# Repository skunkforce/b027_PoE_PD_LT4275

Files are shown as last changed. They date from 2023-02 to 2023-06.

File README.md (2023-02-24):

# edgy_board number b027
This design is part of the [edgy board project](https://github.com/skunkforce/edgy_boards). It provides a PoE Power Device capable of 100W. 

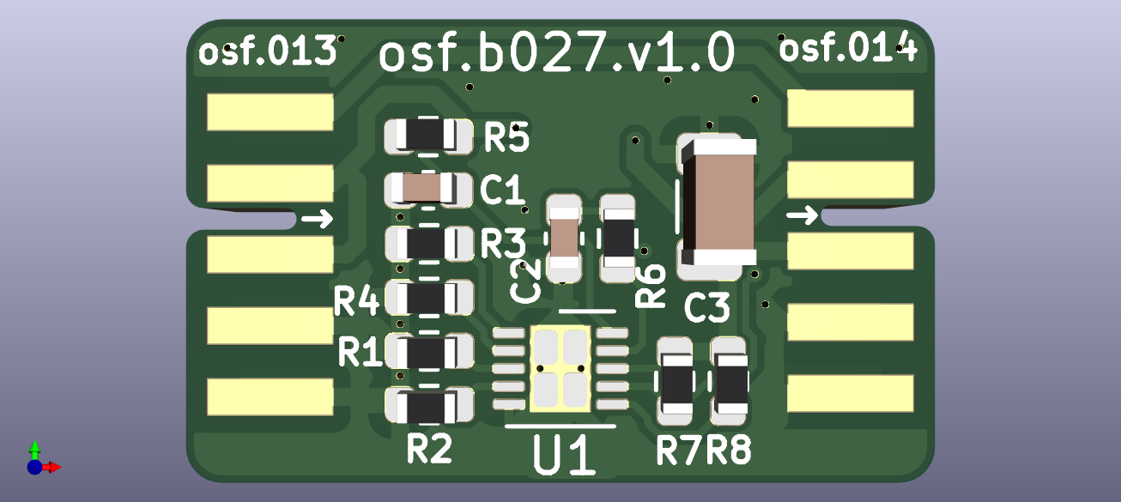
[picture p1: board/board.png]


# getting started
This repository uses submodules. After cloning use the command 

```$ git submodule update --init --recursive```

to pull the submodules before opening the project with kicad. 

# Tests
Tests can be found in [TESTS.md](TESTS.md)

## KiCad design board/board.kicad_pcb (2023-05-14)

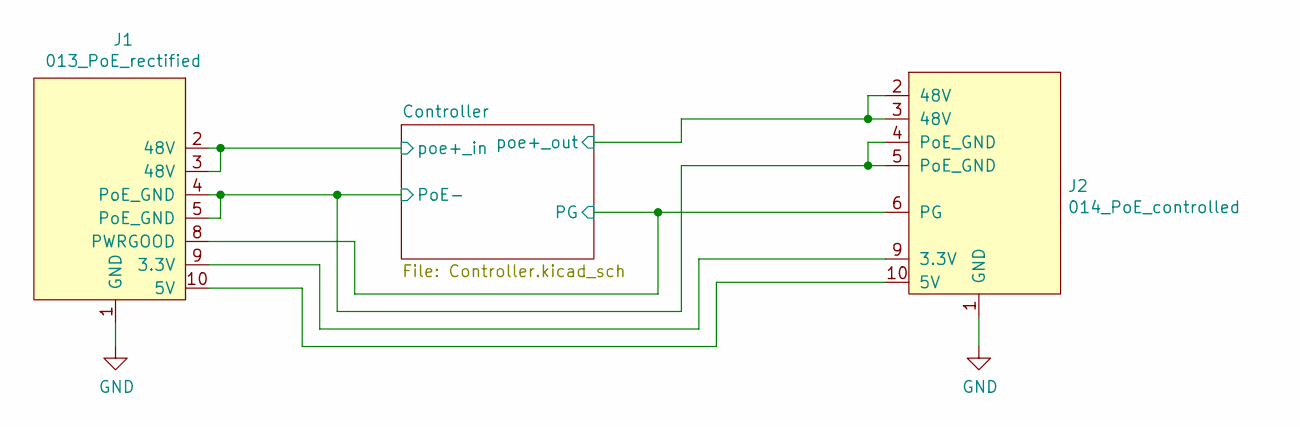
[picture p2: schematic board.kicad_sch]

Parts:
J1: 013_PoE_rectified; on_edge_2x05_device
J2: 014_PoE_controlled; on_edge_2x05_host

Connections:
/Controller/PG: J1.8 (PWRGOOD), J2.6 (PG); also elsewhere on the board
/Controller/PoE-: J1.4 (PoE_GND), J1.5 (PoE_GND), J2.4 (PoE_GND), J2.5 (PoE_GND); also elsewhere on the board
/Controller/poe+_in: J1.2 (48V), J1.3 (48V); also elsewhere on the board
/Controller/poe+_out: J2.2 (48V), J2.3 (48V); also elsewhere on the board
GND: J1.1 (GND), J2.1 (GND)
unnamed: J1.9 (3.3V), J2.9 (3.3V)
unnamed: J1.10 (5V), J2.10 (5V)

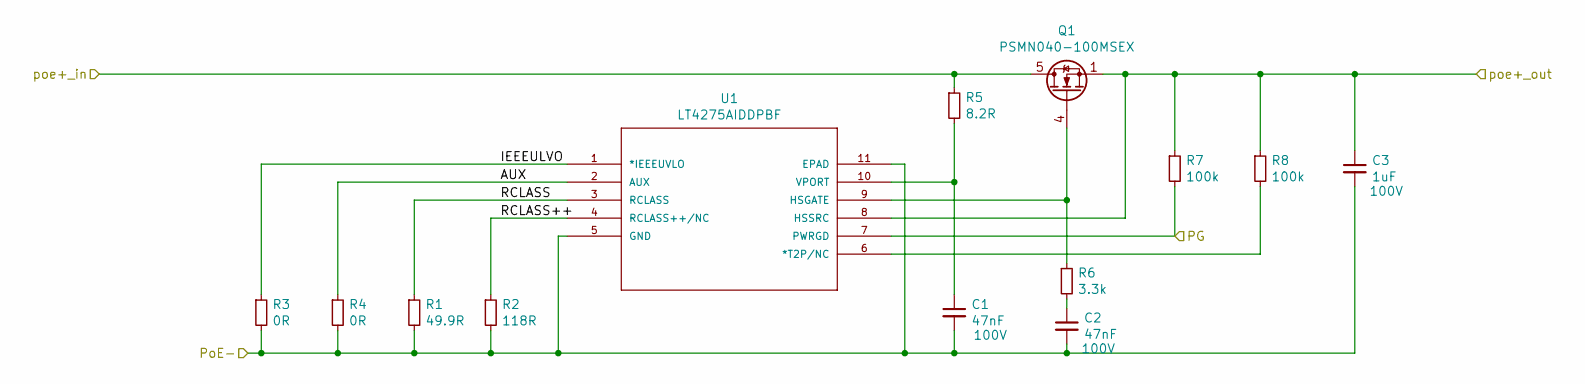
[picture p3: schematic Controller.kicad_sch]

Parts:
C1, C2: 47nF; C_0603_1608Metric; Voltage 100V
C3: 1uF; C_1206_3216Metric; Voltage 100V
Q1: PSMN040-100MSEX; LFPAK33
R1: 49.9R; R_0603_1608Metric
R2: 118R; R_0603_1608Metric
R3, R4: 0R; R_0603_1608Metric
R5: 8.2R; R_0603_1608Metric
R6: 3.3k; R_0603_1608Metric
R7, R8: 100k; R_0603_1608Metric
U1: LT4275AIDDPBF; DFN-10-1EP_3x3mm_P0.5mm_EP1.65x2.38mm_ThermalVias; MANUFACTURER_PART_NUMBER lt4275aidd#pbf

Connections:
/Controller/AUX: R4.1, U1.2 (AUX)
/Controller/IEEEULVO: R3.1, U1.1 (*IEEEUVLO)
/Controller/PG: R7.2, U1.7 (PWRGD); also elsewhere on the board
/Controller/PoE-: C1.2, C2.2, C3.2, R1.2, R2.2, R3.2, R4.2, U1.5 (GND), U1.11 (EPAD); also elsewhere on the board
/Controller/RCLASS: R1.1, U1.3 (RCLASS)
/Controller/RCLASS++: R2.1, U1.4 (RCLASS++/NC)
/Controller/poe+_in: Q1.5 (D), R5.1; also elsewhere on the board
/Controller/poe+_out: C3.1, Q1.1 (S), Q1.2 (S), Q1.3 (S), R7.1, R8.1, U1.8 (HSSRC); also elsewhere on the board
unnamed: C1.1, R5.2, U1.10 (VPORT)
unnamed: C2.1, R6.2
unnamed: Q1.4 (G), R6.1, U1.9 (HSGATE)
unnamed: R8.2, U1.6 (*T2P/NC)

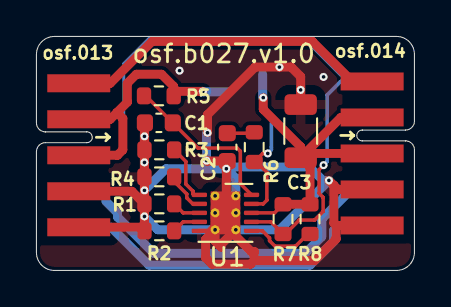
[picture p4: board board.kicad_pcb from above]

Board: 2 copper layers, 21.0 x 13.0 mm, 15 parts (1 on the bottom side), 15 nets.

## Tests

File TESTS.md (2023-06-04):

# initialization test
## setup
Connected 
```mermaid
flowchart LR
  b004 --> b027 
  b027 --> r[1k between pinns 3 and 4 of osf.014 device side]
  
```
## results
initialization works on a standard PoE switch.

# current test
## setup
Connected
```mermaid
flowchart LR
  b004 --> b027 
  b027 --> r[variable resistor between pinns 3 and 4 of osf.014 device side]
  
```
Varied the output inpedence to simulate different loads. Monitored the temperature of the controller and mosfet chips with a thermal camera.
## results
Output stable up to 25 watts (which was the limmit of the test system). Temperature of the mosfet rose by 8°C. This would suggest stable operation well above the test szenario.

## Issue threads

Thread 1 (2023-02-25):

needs modernization

odinthenerd, 2023-02-25:
This board does not meet the design requirements. It needs at least the following:

1. all symbols and footprints need to come either from the KiCad native libraries or the put_on_edge submodule, or a local library.
2. all libraries used need to be included with relative paths
3. the footprints on the boards need to be updated (they have the old large-notch version of the connector)
4. all footprints should have 3D models associated with them
5. the repo needs a board.png

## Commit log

2023-03-01 added schematic and footprint from legacy project
    [board.kicad_pcb, board.kicad_sch, implementation.kicad_sch]
2023-03-01 changed PSMN5R2 footprint from LFPAK33 to LFPAK56
    The PSMN5R2 is not available in LFPAK33.
    [board.kicad_pcb, board.kicad_sch, implementation.kicad_sch]
2023-03-05 Moved Q1 from front to back
    Q1 from front to back and keeped the size of pcb
    [Controller.kicad_sch, board.kicad_pcb, board.kicad_sch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]
2023-05-13 updated connectors
    [Controller.kicad_sch, board.kicad_pcb, board.kicad_sch]
2023-05-14 added power doo cinnection upstream
    [board.kicad_pcb, board.kicad_sch]
